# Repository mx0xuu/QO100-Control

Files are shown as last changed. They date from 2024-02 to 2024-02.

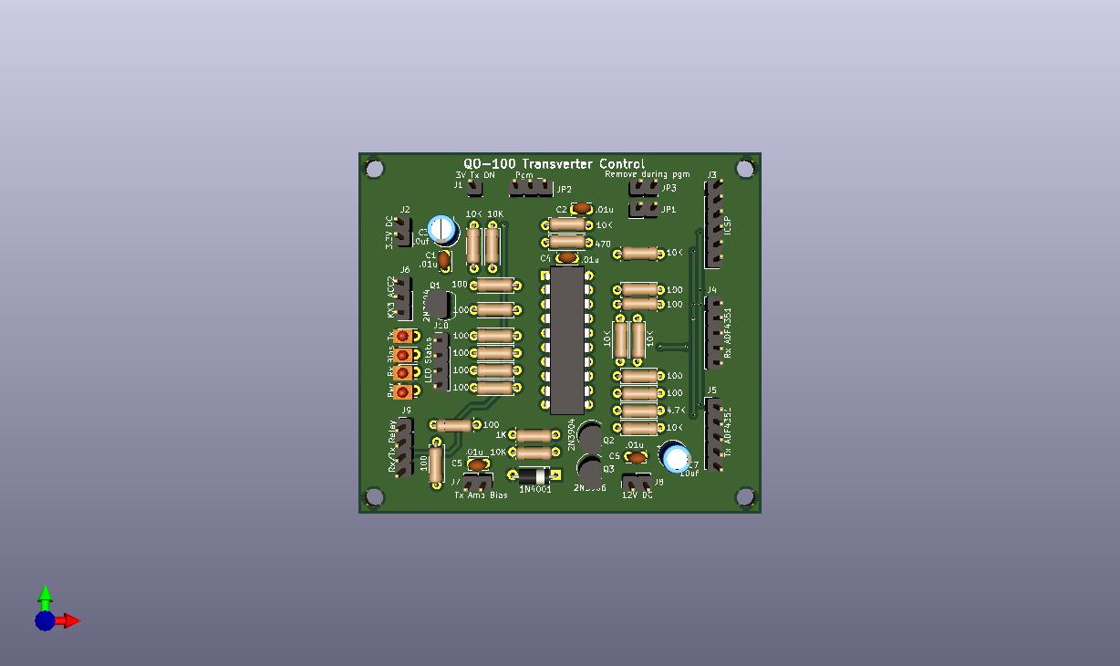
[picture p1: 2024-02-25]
QO100_Control_PCB_V2.jpg

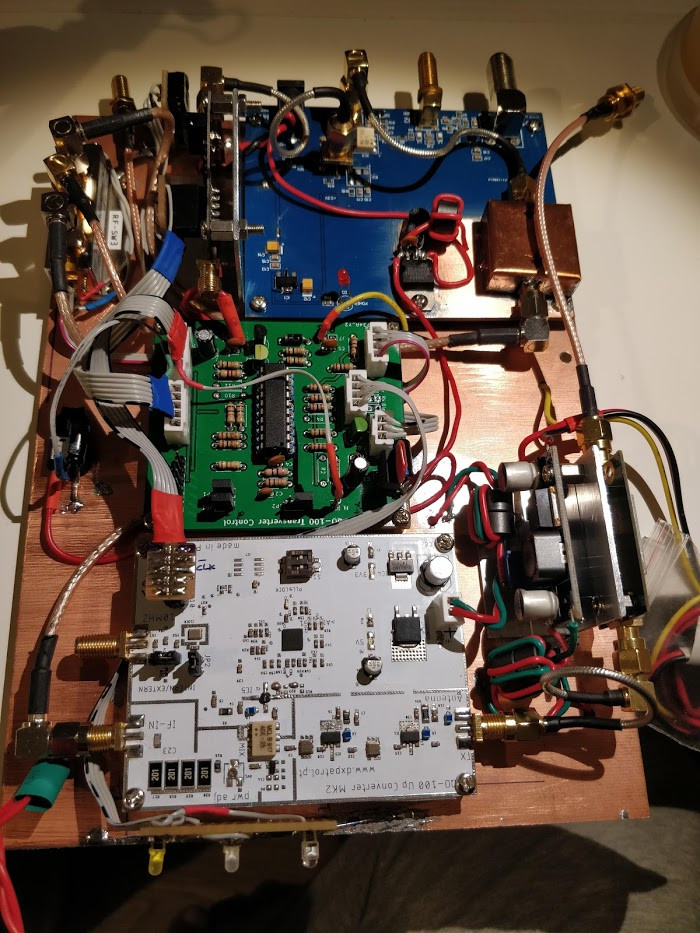
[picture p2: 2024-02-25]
inside.jpg

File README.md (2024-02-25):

# QO100-Control
Transverter control for QO100

## What is it ?
PIC based controller which will generate the required frequencies for both up-converter (DX Patrol) and down-converter. This controller will also use the PTT (SEND) from the IF Transceiver, squence the keying of RX/TX and powering of power amp.

The software is developed for PIC16F18444

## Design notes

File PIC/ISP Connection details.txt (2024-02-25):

ISP				16F84A/16F628	12F675		DX Patrol SV1 Pin		16F18444

1	MCLR			Pin #4		Pin #4		Pin #9 (MCLR)			Pin #4
2	VDD			Pin #14		Pin #1		Pin #7 (DC+)			Pin #1
3 	VSS (GND)		Pin #5		Pin #8		Pin #5 (GND)			Pin #20
4	PGD/ICSPDAT (DATA)	Pin #13		Pin #7		Pin #1 (Data)			Pin #19
5	PGC/ICSPCLK (CLK)	Pin #12		Pin #6		Pin #4 (Clock)			Pin #18
6	PGM (LVP)

ADF4351 Register update 
	16F18444		AD4351 Board	DX Partol SV1	
DATA	Pin #19			Pin #5		Pin #1
CLK	Pin #18			Pin #4		Pin #4
LE	Pin #17			Pin #6		Pin #3
CE	Pin #13(Rx)/#12(TX)	Pin #8		Pin #6
MUX				Pin #3		Pin #8
GND	Pin #20			Pin #10		Pin #5
3v3	Pin #1			Pin #9		Pin #7 (Donot Connect)

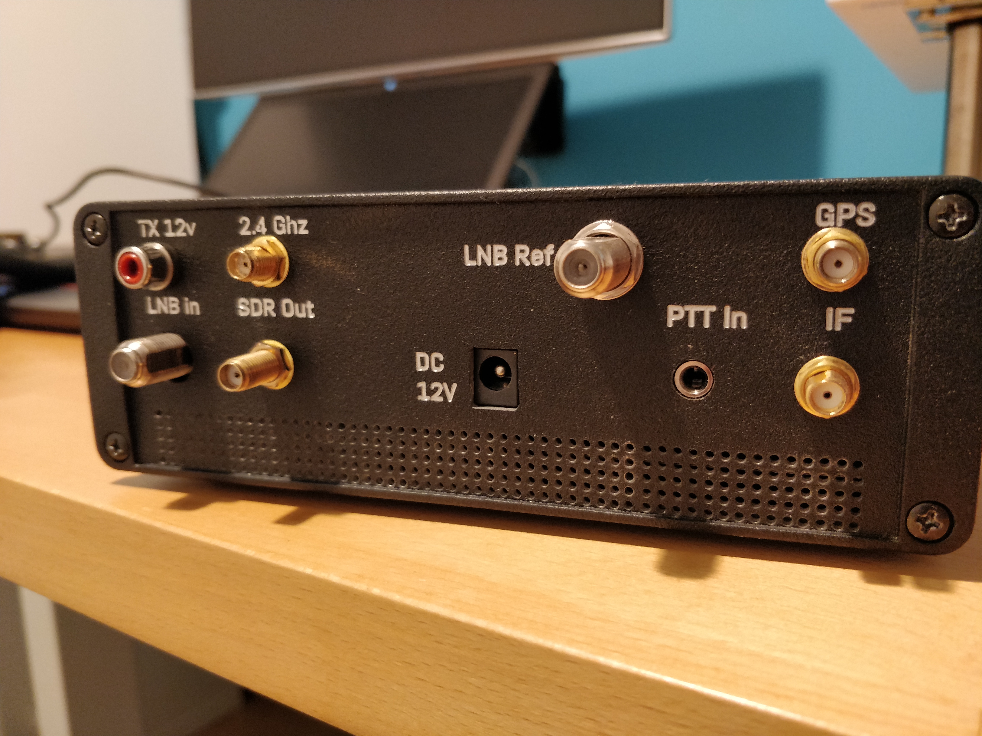
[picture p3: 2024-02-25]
rear panel.jpg

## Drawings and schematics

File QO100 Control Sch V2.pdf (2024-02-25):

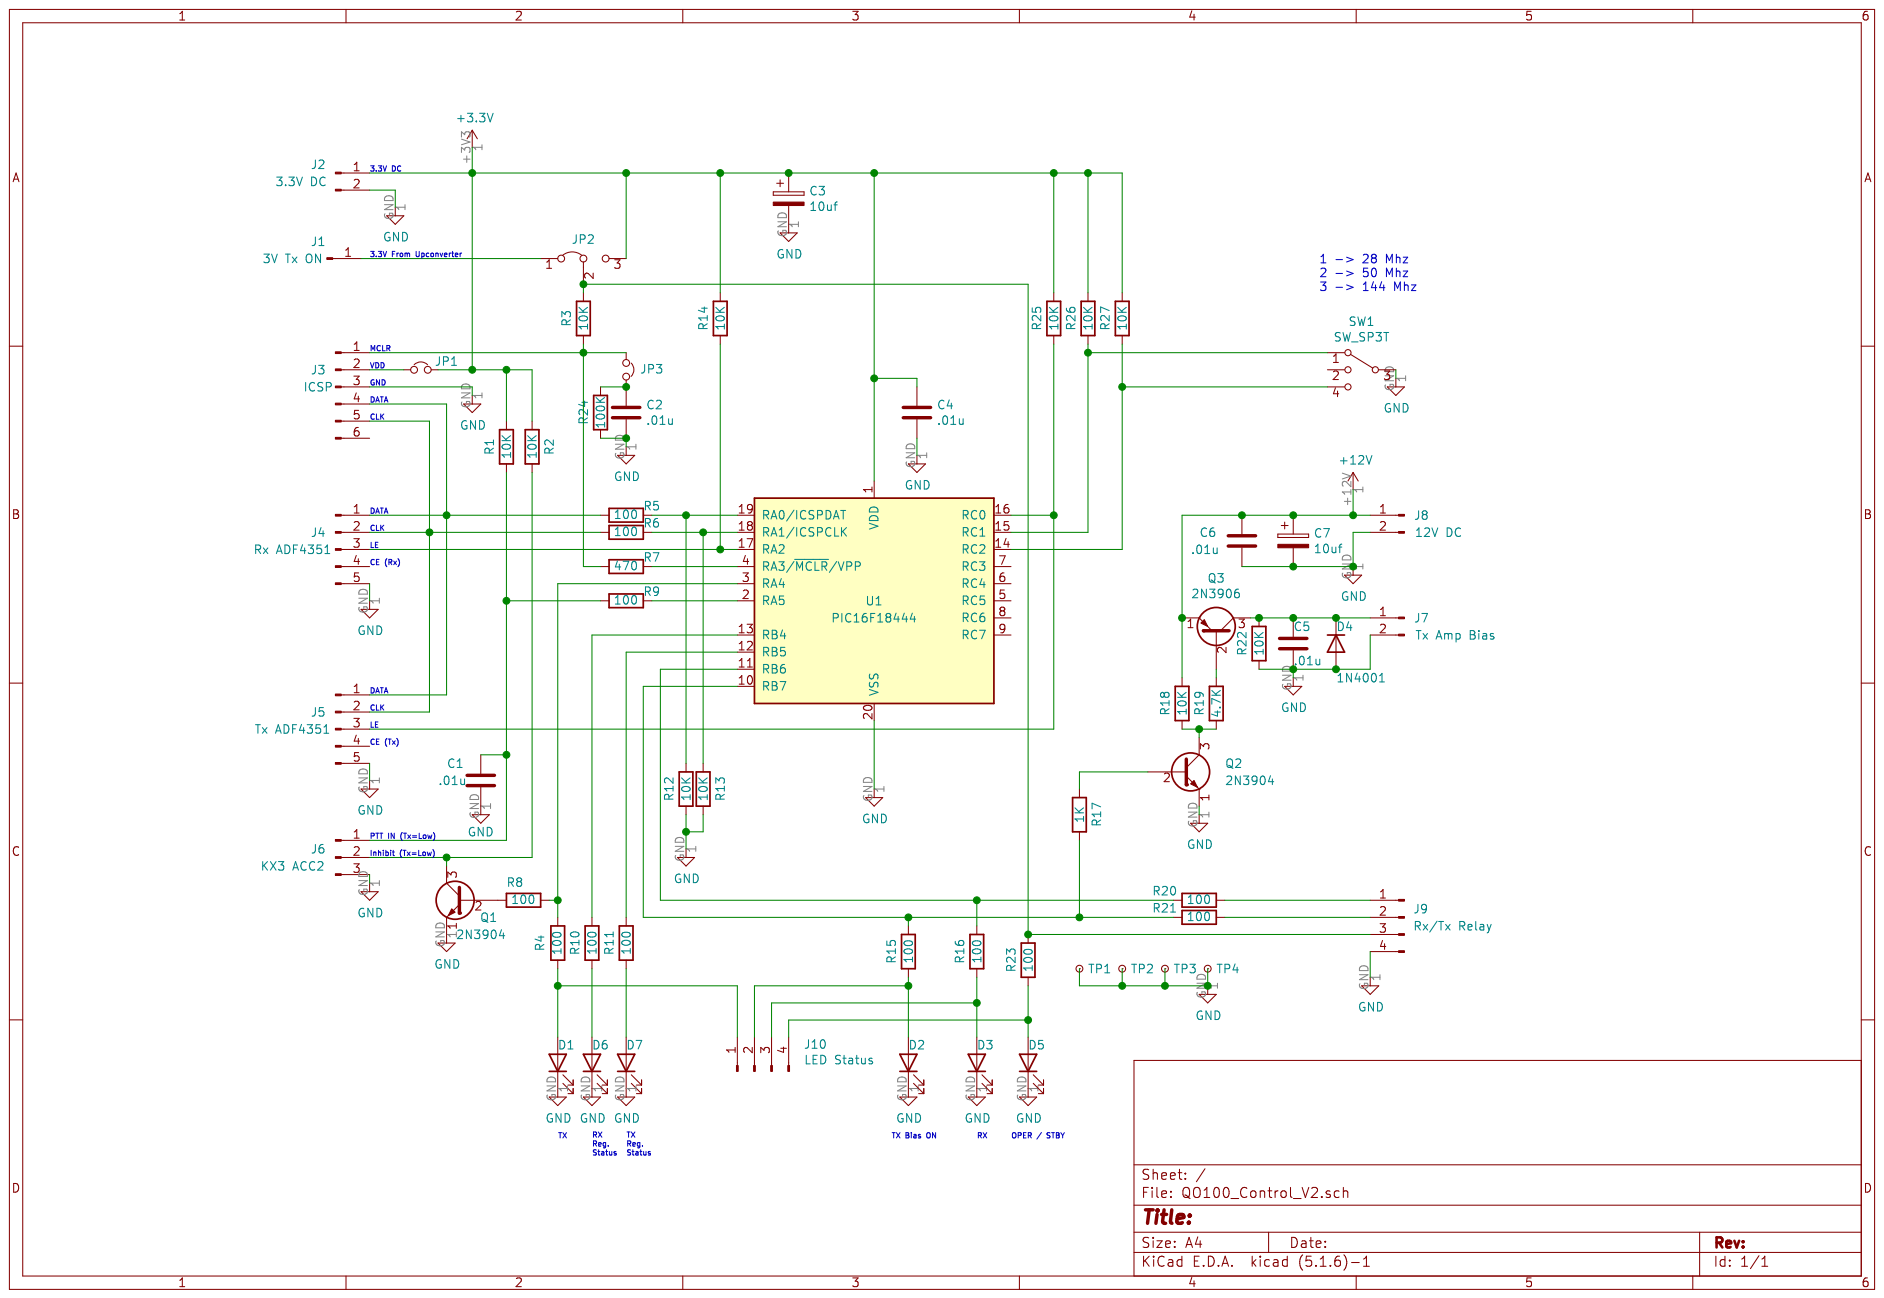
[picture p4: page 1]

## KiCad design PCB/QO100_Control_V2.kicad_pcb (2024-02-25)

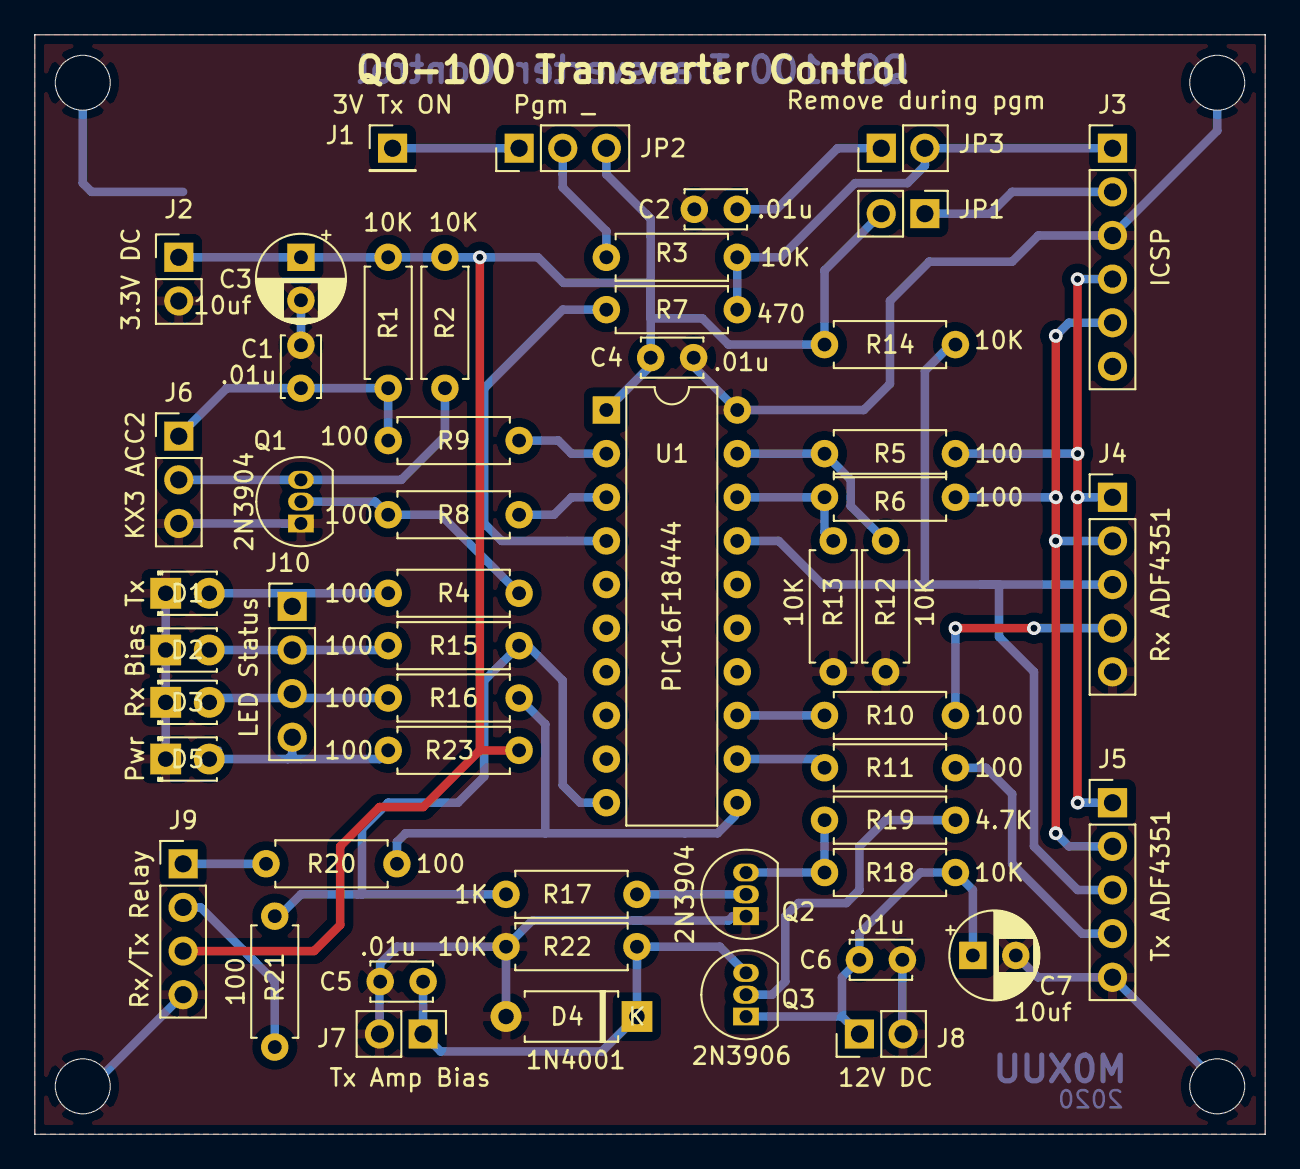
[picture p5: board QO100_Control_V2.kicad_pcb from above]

Board: 2 copper layers, 71.6 x 64.0 mm, 56 parts (0 on the bottom side), 35 nets.

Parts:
C1, C2, C4, C5, C6: .01u; C_Disc_D3.4mm_W2.1mm_P2.50mm
C3, C7: 10uf; CP_Radial_D5.0mm_P2.50mm
D1, D2, D3, D5: LED; LED_D1.8mm_W3.3mm_H2.4mm
D4: 1N4001; D_A-405_P7.62mm_Horizontal
J1: 3V Tx ON; PinHeader_1x01_P2.54mm_Vertical
J2: 3.3V DC; PinHeader_1x02_P2.54mm_Vertical
J3: ICSP; PinHeader_1x06_P2.54mm_Vertical
J4: Rx ADF4351; PinHeader_1x05_P2.54mm_Vertical
J5: Tx ADF4351; PinHeader_1x05_P2.54mm_Vertical
J6: KX3 ACC2; PinHeader_1x03_P2.54mm_Vertical
J7: Tx Amp Bias; PinHeader_1x02_P2.54mm_Vertical
J8: 12V DC; PinHeader_1x02_P2.54mm_Vertical
J9: Rx/Tx Relay; PinHeader_1x04_P2.54mm_Vertical
J10: LED Status; PinHeader_1x04_P2.54mm_Vertical
JP1, JP3: Remove during pgm; PinHeader_1x02_P2.54mm_Vertical
JP2: Pgm _; PinHeader_1x03_P2.54mm_Vertical
Q1, Q2: 2N3904; TO-92_Inline
Q3: 2N3906; TO-92_Inline
R1, R2, R3, R12, R13, R14, R18, R22: 10K; R_Axial_DIN0207_L6.3mm_D2.5mm_P7.62mm_Horizontal
R4, R5, R6, R8, R9, R10, R11, R15, R16, R20, R21, R23: 100; R_Axial_DIN0207_L6.3mm_D2.5mm_P7.62mm_Horizontal
R7: 470; R_Axial_DIN0207_L6.3mm_D2.5mm_P7.62mm_Horizontal
R17: 1K; R_Axial_DIN0207_L6.3mm_D2.5mm_P7.62mm_Horizontal
R19: 4.7K; R_Axial_DIN0207_L6.3mm_D2.5mm_P7.62mm_Horizontal
TP1, TP2, TP3, TP4: M3; MountingHole_3.2mm_M3
U1: PIC16F18444; DIP-20_W7.62mm

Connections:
+3V3: C3.1, C4.1, J2.1, J9.3, JP1.2, JP2.3, R1.1, R2.1, R14.1, R23.1, U1.1
+12V: C6.1, C7.1, J8.1, Q3.1, R18.1
GND: C1.2, C2.2, C3.2, C4.2, C5.2, C6.2, C7.2, D1.1, D2.1, D3.1, D4.2, D5.1, J2.2, J3.3, J4.5, J5.5, J6.3, J7.2, J8.2, J9.4, Q1.1, Q2.1, R12.2, R13.2, R22.2, TP1.1, TP2.1, TP3.1, TP4.1, U1.20
unnamed: C1.1, J6.1, R1.2, R9.1
unnamed: C2.1, JP3.1
unnamed: C5.1, D4.1, J7.1, Q3.3, R22.1
unnamed: D1.2, J10.1, R4.1
unnamed: D2.2, J10.2, R15.2
unnamed: D3.2, J10.3, R16.2
unnamed: D5.2, J10.4, R23.2
unnamed: J1.1, JP2.1
unnamed: J3.1, JP3.2, R3.2, R7.1
unnamed: J3.2, JP1.1
unnamed: J3.4, J4.1, J5.1, R5.1
unnamed: J3.5, J4.2, J5.2, R6.1
unnamed: J4.3, J5.3, R14.2, U1.17
unnamed: J4.4, R10.1
unnamed: J5.4, R11.1
unnamed: J6.2, Q1.3, R2.2
unnamed: J9.1, R20.2
unnamed: J9.2, R21.2
unnamed: JP2.2, R3.1
unnamed: Q1.2, R4.2, R8.1
unnamed: Q2.2, R17.1
unnamed: Q2.3, R18.2, R19.2
unnamed: Q3.2, R19.1
unnamed: R7.2, U1.4
unnamed: R8.2, U1.3
unnamed: R9.2, U1.2
unnamed: R10.2, U1.13
unnamed: R11.2, U1.12
unnamed: R5.2, R12.1, U1.19
unnamed: R6.2, R13.1, U1.18
unnamed: R15.1, R17.2, R21.1, U1.10
unnamed: R16.1, R20.1, U1.11

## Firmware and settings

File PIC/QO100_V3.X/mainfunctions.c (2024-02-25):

/* 
 * File:   mainfunction.c
 * Author: User
 *
 * Created on August 27, 2021, 8:52 PM
 */

#include "mainfunctions.h"
#include "mcc_generated_files/mcc.h"

unsigned char G_STBY_STATE;                     // 0 = StandBy(No Tx), 1 = Operate Mode (Tx Possible)
unsigned char G_PTT_STATE;                      // 0 = RX, 1 = TX
unsigned char G_IF_SEL_STATE;                   // Copy of PORTC
unsigned char G_PORTC_OLD;

// Set the registers, These will be moved to EE memory at a later stage.
unsigned long rx_reg[6];
unsigned long tx_reg[6];

// 28 Mhz IF (RX = 711.0 Mhz, Ref: 25 Mhz, -1 dBm, 100Khz) 
unsigned long rx_reg_28[6] = {0x388098, 0x80080C9, 0x4E42, 0x4B3, 0xAC802C, 0x580005}; //
// 28 Mhz IF (TX = 2371.5 Mhz, Ref: 25 Mhz, +5 dBm, 100Khz)
unsigned long tx_reg_28[6] = {0x2F0158, 0x8008191, 0x18005E42, 0x4B3, 0x8C823C, 0x580005}; //

// 50 Mhz IF (RX = 689.0 Mhz, Ref: 25 Mhz, -1 dBm, 100Khz) 
unsigned long rx_reg_50[6] = {0x370030, 0x80080C9, 0x4E42, 0x4B3, 0xAC802C, 0x580005}; //
// 50 Mhz IF (TX = 2349.5 Mhz, Ref: 25 Mhz, +5 dBm, 100Khz)
unsigned long tx_reg_50[6] = {0x2E8188, 0x8008191, 0x18005E42, 0x4B3, 0x8C823C, 0x580005};//

// 144 Mhz IF (RX = 595.0 Mhz, Ref: 25 Mhz, -1 dBm, 100Khz) 
unsigned long rx_reg_144[6] = {0x2F8008, 0x8008029, 0x4E42, 0x4B3, 0xAC802C, 0x580005};
// 144 Mhz IF (TX = 2255.5 Mhz, Ref: 25 Mhz, +5 dBm, 100Khz)
unsigned long tx_reg_144[6] = {0x2D0058, 0x8008191, 0x18005E42, 0x4B3, 0x8C823C, 0x580005}; 

// Functions starts here
void blink_status_rx(int count_val, char duration_val)
{
    REG_STATUS_RX_SetLow();
    __delay_us(10);
    for (int i = 0; i < count_val; i++)
    {
        REG_STATUS_RX_Toggle();
        if (duration_val == 'S')
            __delay_us(50000);
        else
            __delay_us(500000);
    }
    REG_STATUS_RX_SetLow();
}

void blink_status_tx(int count_val, int duration_val)
{
    REG_STATUS_TX_SetLow();
    __delay_us(10);
    for (int i = 0; i < count_val; i++)
    {
        REG_STATUS_TX_Toggle();   
        if (duration_val == 'S')
            __delay_us(50000);
        else
            __delay_us(500000);
    }
    REG_STATUS_TX_SetLow();
}

void SetRelay_Rx()
{
    RLY_RX_OUT_SetHigh();                                     // Set RLY to RX
    RLY_TX_OUT_SetLow();                                     // Set RLY to RX
    __delay_us(10);
}

void SetRelay_Tx()
{
    RLY_TX_OUT_SetHigh();                                     // Set RLY to TX
    RLY_RX_OUT_SetLow();                                     // Set RLY to TX
    __delay_us(10);
}

void SetTxInhibit_ON()
{
    TRX_INHIBIT_OUT_SetHigh();
}

void SetTxInhibit_OFF()
{
    TRX_INHIBIT_OUT_SetLow();
}

void WriteRegister32(unsigned long value) 
{
    for (int i = 31; i >= 0; i--)                       //Program a 32bit register
    {
        ADF4351_DATA_PORT = (value & 0x80000000) ? 1 : 0;    // Send Data
        __delay_us(5);
        ADF4351_CLK_SetHigh();                                // Send CLK
        __delay_us(5);
        ADF4351_CLK_SetLow();
        __delay_us(5);
        value <<= 1;                                    // Next bit
    }
}

void SetADF4351_Rx() // Program 6 RX ADF4351 registers
{
    for (int i = 5; i >= 0; i--)                // Program RX ADF4351 starting with R5
    {
        ADF4351_LE_RX_SetLow();
        __delay_us(10);
        WriteRegister32(rx_reg[i]);
        ADF4351_LE_RX_SetHigh();                      // latch data into register
        __delay_us(10);
        ADF4351_LE_RX_SetLow();
        __delay_us(10);
        ADF4351_DATA_SetLow();
        __delay_us(10);
    }
    __delay_us(500);
}

void SetADF4351_Tx() // Program 6 RX ADF4351 registers
{
    for (int i = 5; i >= 0; i--)                // program ADF4351 starting with R5
    {
        ADF4351_LE_TX_SetLow();
        __delay_us(10);
        WriteRegister32(tx_reg[i]);
        ADF4351_LE_TX_SetHigh();                      // latch data into register
        __delay_us(10);
        ADF4351_LE_TX_SetLow();
        __delay_us(10);
        ADF4351_DATA_SetLow();
        __delay_us(10);
    }
    __delay_us(500);
}

void SwitchToRx()
{
    SetTxInhibit_OFF();                     // Set TX Inhibit to LOW
    __delay_us(500);
    SetRelay_Rx();                          // Switch RLY to RX
    __delay_us(500);
}

void SwitchToTx()
{
    SetRelay_Tx();                          // Switch RLY to TX
    __delay_us(500);
    SetTxInhibit_ON();                      // Set TX Inhibit to HIGH
    __delay_us(500);
}

void CheckIF() // Check and Set Reg values 
{
    if (G_PORTC_OLD != PORTC)   // Only when there is a change
    {
        if ((IF_SEL_28_GetValue() == 1) && (IF_SEL_144_GetValue() == 1))
        {   // Set Reg. values for 50 Mhz IF
            for (int i = 0; i <= 5; i++)
            {
                rx_reg[i] = rx_reg_50[i];
                tx_reg[i] = tx_reg_50[i];
            }
            blink_status_rx(1, 'S');
            blink_status_tx(1, 'S');
        }
        else if (IF_SEL_28_GetValue() == 0)
        {   // Set Reg. values for 28 Mhz IF
            for (int i = 0; i <= 5; i++)
            {
                rx_reg[i] = rx_reg_28[i];
                tx_reg[i] = tx_reg_28[i];
            }
            blink_status_rx(1, 'S');
            blink_status_tx(1, 'S');
        }
        else if (IF_SEL_144_GetValue() == 0)
        {   // Set Reg. values for 144 Mhz IF
            for (int i = 0; i <= 5; i++)
            {
                rx_reg[i] = rx_reg_144[i];
                tx_reg[i] = tx_reg_144[i];
            }
            blink_status_rx(1, 'S');
            blink_status_tx(1, 'S');
        }    
        
        // Update RX registers in all cases
        SetADF4351_Rx();            
        blink_status_rx(1, 'L');
                
        // Also set the TX registers if STBY is ON
        if ((UPCONV_STBY_IN_GetValue() == 1) && (G_STBY_STATE == 1))
        {
            SetADF4351_Tx();            // Set TX Freq. registers
            blink_status_tx(1, 'L');
        }

        G_PORTC_OLD = PORTC;
        __delay_us(5);

    } 
    else
    {
        // No change to PORTC - do nothing
    }

}

void CheckStandBy() // Check Standby is enabled.
{
    if ((UPCONV_STBY_IN_GetValue() == 0) && (G_STBY_STATE == 1))
    {
        // During Start-up or when Tx > Rx, Set to RX (in STBY mode).
        SwitchToRx();               // Switch to RX3
        G_STBY_STATE = 0;           // Current Mode is Standby (no TX)
    }
    else if ((UPCONV_STBY_IN_GetValue() == 1) && (G_STBY_STATE == 0))
    {
        SetADF4351_Tx();            // Set TX Freq. registers
        G_STBY_STATE = 1;           // Current Mode is Operate (TX possible)
    }
}

void CheckPTT() // Set TRX relay                                 
{
    if (G_STBY_STATE == 1) // Only when StandBy is ON
    {
        //if ((TRX_PTT_IN_GetValue() == 0) && (G_PTT_STATE))
        if (TRX_PTT_IN_GetValue() == 0)
        {
            // PTT Pin is Low and G_PTT_STATE set by Interrupt 
            SwitchToTx(); // TX
        }
        //else if ((TRX_PTT_IN_GetValue() == 1) && (G_PTT_STATE))
        else if (TRX_PTT_IN_GetValue() == 1)
        {
            // PTT Pin is high and G_PTT_STATE is also high, ie Switching from TX to RX
            SwitchToRx(); // RX
            G_PTT_STATE = 0;
        }
    }
}

/*
void SetPTT_State()
{
    if ((IOCAN5 == 1) && (IOCAF5 == 1))
    {
        // Set Global PTT status
        G_PTT_STATE = 1;
    }
    IOCAF5 = 0;
}

void __interrupt() handle_interrupt(void) // interrupt function
{
    if ((IOCIE == 1 && IOCIF == 1))
    {
        SetPTT_State();
        IOCIF = 0;
    }
}
*/

void app_setup()
{
    G_PORTC_OLD = 0b00000000;           // Initialise OLD value for PORTC
    G_PTT_STATE = 0;                    // PTT State - set by the interrupt
    if (UPCONV_STBY_IN_GetValue() == 0)            // During start up if STBY sw is 0; Only set RX
    {
        G_STBY_STATE = 1;               // Set STBY State = 1; In main() this will result 
    }                                   // in setting RX freq
    else if (UPCONV_STBY_IN_GetValue() == 1)       // During start up if STBY sw is 1; Set RX now
    {                                   // in main() TX freq will also be set
        SwitchToRx();                   // Switch to RX
        G_STBY_STATE = 0;
    }
    REG_STATUS_RX_SetLow();
    REG_STATUS_TX_SetLow();
}

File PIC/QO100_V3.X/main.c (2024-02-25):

/**
  Generated Main Source File

  Company:
    Microchip Technology Inc.

  File Name:
    main.c

  Summary:
    This is the main file generated using PIC10 / PIC12 / PIC16 / PIC18 MCUs

  Description:
    This header file provides implementations for driver APIs for all modules selected in the GUI.
    Generation Information :
        Product Revision  :  PIC10 / PIC12 / PIC16 / PIC18 MCUs - 1.81.7
        Device            :  PIC16F18444
        Driver Version    :  2.00
*/

/*
    (c) 2018 Microchip Technology Inc. and its subsidiaries. 
    
    Subject to your compliance with these terms, you may use Microchip software and any 
    derivatives exclusively with Microchip products. It is your responsibility to comply with third party 
    license terms applicable to your use of third party software (including open source software) that 
    may accompany Microchip software.
    
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
    IN NO EVENT WILL MICROCHIP BE LIABLE FOR ANY INDIRECT, SPECIAL, PUNITIVE, 
    INCIDENTAL OR CONSEQUENTIAL LOSS, DAMAGE, COST OR EXPENSE OF ANY KIND 
    WHATSOEVER RELATED TO THE SOFTWARE, HOWEVER CAUSED, EVEN IF MICROCHIP 
    HAS BEEN ADVISED OF THE POSSIBILITY OR THE DAMAGES ARE FORESEEABLE. TO 
    THE FULLEST EXTENT ALLOWED BY LAW, MICROCHIP'S TOTAL LIABILITY ON ALL 
    CLAIMS IN ANY WAY RELATED TO THIS SOFTWARE WILL NOT EXCEED THE AMOUNT 
    OF FEES, IF ANY, THAT YOU HAVE PAID DIRECTLY TO MICROCHIP FOR THIS 
    SOFTWARE.
*/

#include "mcc_generated_files/mcc.h"
#include "mainfunctions.h"

/*
                         Main application
 */
void main(void)
{
    // initialize the device
    SYSTEM_Initialize();

    // Enable the Global Interrupts
    INTERRUPT_GlobalInterruptEnable();

    // Enable the Peripheral Interrupts
    INTERRUPT_PeripheralInterruptEnable();

    // Disable the Global Interrupts
    //INTERRUPT_GlobalInterruptDisable();

    // Disable the Peripheral Interrupts
    //INTERRUPT_PeripheralInterruptDisable();
    // Application Setup
    app_setup();                            // Setup
    
    while (1)
    {
        CheckIF();                      // Get the IF Freq. selection
        CheckStandBy();                 // Check STBY and prepare for TX
        CheckPTT();                     // Check PTT and set to TX/RX
    }
}
/**
 End of File
*/
